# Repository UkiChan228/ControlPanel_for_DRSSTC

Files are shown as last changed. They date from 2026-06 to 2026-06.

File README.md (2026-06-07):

# ControlPanel for DRSSTC (RP2350)

Universal, open-source control panel for Dual Resonant Solid State Tesla Coils (DRSSTC) based on the Raspberry Pi RP2350.

Platform
Status

<br/>

### Table of Contents
<p>
  <a href="#-overview">Overview</a> <br/>
  <a href="#-status">Status</a> <br/>
  <a href="#-getting-started">Getting Started</a> <br/>
  <a href="#-hardware-choices">Hardware Choices</a> <br/>
  <a href="#-project-history">Project History</a>
</p>

<br/>

## 📒 Overview

This project is a dedicated, portable controller for **DRSSTC (Dual Resonant Solid State Tesla Coils)**. Built around the Raspberry Pi **RP2350**, it integrates reliable, high-frequency power management, an IPS touchscreen interface, and critical hardware-level safety features required for high-voltage control.

The primary goal is to provide a robust, noise-immune controller that can reliably send pulses to a Tesla coil over fiber optics without risking signal corruption from electromagnetic interference (EMI).

---

## ⚠️ Status

> [!WARNING]
> This project is currently in the **Alpha** development phase. The core hardware architecture is established, but firmware and features are actively being updated. Treat it as experimental.

---
### 3D Screenshot

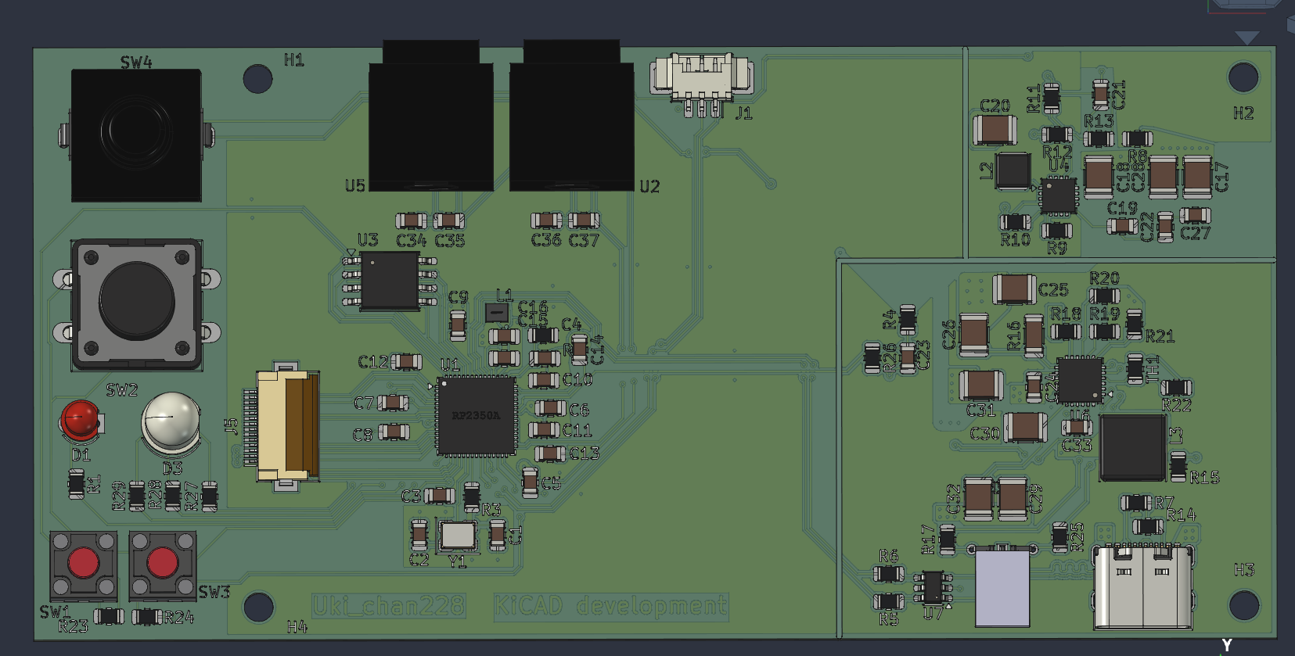
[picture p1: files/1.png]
Screnshoot1

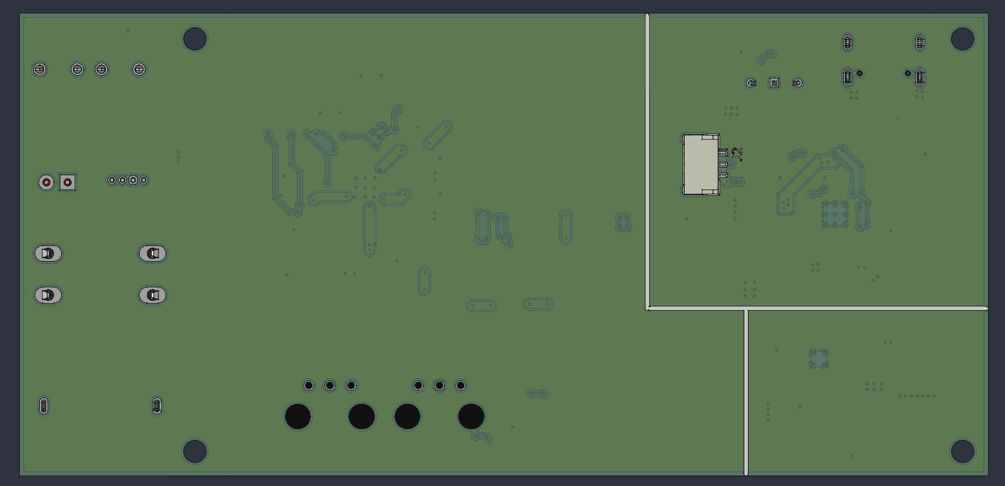
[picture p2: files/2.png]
Screnshoot2

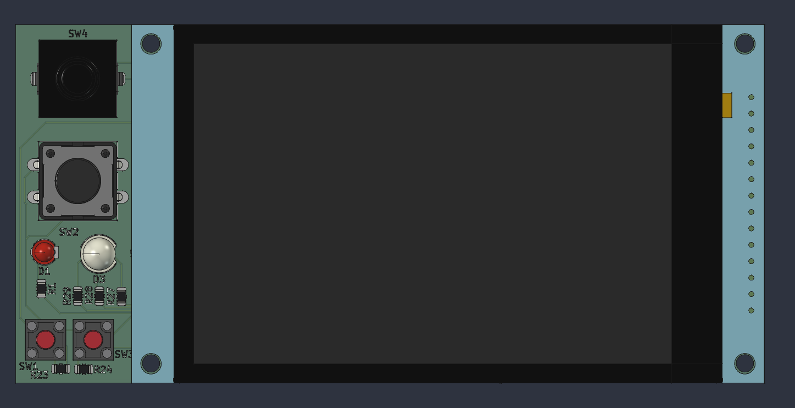
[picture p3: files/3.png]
Screnshoot3


---

## 🧑‍💻 Getting Started

To clone the repository along with the required submodules for graphics libraries and drivers, run:

```bash
# Clone the repository
git clone https://codeberg.org/uki_chan228/ControlPanel_for_DRSSTC  

# Initialize and update submodules and lvgl-9.5.0
cd ControlPanel_for_DRSSTC
git submodule update --init --recursive
```

---

## Hardware Architecture & Design Choices

### 1. MCU: Why RP2350 and not STM32?
Why did I choose the **RP2350** instead of something like the **STM32H507** or other H-series STM32 chips? It came down to high costs and counterfeits. If you want to buy an inexpensive **STM32** on AliExpress, almost all of them turn out to be clones or fakes. If you do manage to find an original, the price is quite steep. As a reliable example of genuine hardware, we can look at WeAct Studio. They have an excellent reputation, sell original dev boards, and their GitHub is an amazing resource containing schematics for all of their modules. Currently, the **RP2350** from **WeAct Studio** costs about $3. By comparison, the **STM32H** and **STM32G** series cost anywhere from $5.50 to $10. Of course, those offer more processing power and higher-quality peripherals like timers—after all, the STM32 architecture is time-tested and highly trusted. 

If we look at **STM32** alternatives, we should also mention Chinese compatible MCUs like the **AT32, GD32, APM32,** and CH32. These are essentially enhanced clones of the original **STM32**. Out of these four, GD32 (highly preferred) and **AT32** are the best choices and represent solid, reliable options to buy on AliExpress. 

But let's return to the RP2350. Its absolute killer feature is the PIO (Programmable I/O)—tiny state machines/microprocessors that run completely independently of the main CPU cores. The **RP2350** features three PIO blocks with 3 state machines each, giving you 12 independent processors in total. It is essentially a mini-FPGA built right into a microcontroller! This lets you implement almost any proprietary interface or even design your own. This is incredibly useful for my Remote Control project because I can send control pulses to a Tesla coil via fiber optics. I don't have to worry about what happens if the main processor hangs or if another button is pressed, because these tasks are handled by entirely separate hardware subsystems within the same silicon die.

In short, the RP2350 wins on cost-efficiency and unique features that can easily replace much more expensive **STM32** chips. Plus, it's a very new chip, which is also a great advantage.

### 2. Display and UI
The UI runs on an **MSP3526**, a 3.5-inch IPS display (480x320) with a capacitive touchscreen. The IPS panel allows for 16 million colors, making it comfortable to view real-time diagnostic graphs and navigate menus. 

*Safety feature:* To prevent accidental triggers, touchscreen interrupts are completely ignored at the firmware level while the RP2350 is actively transmitting pulses to the coil.

### 3. Power Supply
The board is powered by two **18650 Li-ion cells** mounted symmetrically for physical balance. 

For voltage regulation, I used the **TLV62130** step-down buck converter. I actually borrowed this idea from the Antminer S9 control boards (which use five of them). It operates at a high switching frequency (1.25MHz - 2.5MHz). Because of this high frequency, voltage ripple is minimal, and there is no need for massive filtering capacitors. It is also extremely durable, having been proven in harsh ASIC mining environments.

Charging the 2S battery pack is handled by an **IP2326** IC, which is a dedicated, highly efficient switching charger for 2-series lithium setups.

All components were selected so they can be easily sourced from AliExpress, allowing anyone to replicate this build.

---

## Project History & Acknowledgments

This project has been in active development from late January 2026 to June. It represents the time and effort of a single teenager fascinated by high-voltage engineering.

It originally started as a simple breadboard project with an ATmega328P, a character LCD1602, a rotary encoder, and a single start button. By mid-April, new ideas naturally pushed the development further, eventually evolving into the RP2350-based device you see today.

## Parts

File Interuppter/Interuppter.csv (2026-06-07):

Reference | Qty | Value | DNP | Exclude from BOM | Exclude from Board | Footprint | Datasheet
C1,C2 | 2 | 12pF |  |  |  | Capacitor_SMD:C_0805_2012Metric
C3,C6,C7,C8,C9,C10,C11,C12,C13,C23 | 10 | 0.1uF |  |  |  | Capacitor_SMD:C_0805_2012Metric
C4 | 1 | 4,7uF |  |  |  | Capacitor_SMD:C_0805_2012Metric
C5,C15,C16 | 3 | 4.7uF |  |  |  | Capacitor_SMD:C_0805_2012Metric
C14 | 1 | 2.2uF |  |  |  | Capacitor_SMD:C_0805_2012Metric
C17,C18,C25,C26,C28,C31,C32 | 7 | 10uF |  |  |  | Capacitor_SMD:C_1210_3225Metric
C19 | 1 | 33nF |  |  |  | Capacitor_SMD:C_0805_2012Metric
C20,C29,C30 | 3 | 22uF |  |  |  | Capacitor_SMD:C_1210_3225Metric
C21,C22,C24,C27,C33,C34,C36 | 7 | 100nF |  |  |  | Capacitor_SMD:C_0805_2012Metric
C35,C37 | 2 | 30pF |  |  |  | Capacitor_SMD:C_0805_2012Metric
D1 | 1 | LED_START |  |  |  | LED_THT:LED_D3.0mm
D2 | 1 |  |  |  |  | my_details:LED_AKA
D3 | 1 | LED_RAGB |  |  |  | LED_THT:LED_D5.0mm-4_RGB
J1,J2 | 2 | Conn_01x03 |  |  |  | Connector_Molex:Molex_PicoBlade_53261-0371_1x03-1MP_P1.25mm_Horizontal
J4 | 1 | USB_C_Receptacle_USB2.0_16P |  |  |  | Connector_USB:USB_C_Receptacle_G-Switch_GT-USB-7010ASV | https://www.usb.org/sites/default/files/documents/usb_type-c.zip
J5 | 1 | Display |  |  |  | Connector_FFC-FPC:Hirose_FH12-14S-0.5SH_1x14-1MP_P0.50mm_Horizontal
L1 | 1 | 3.3uH |  |  |  | RP2350_60QFN_minimal:L_pol_2016
L2 | 1 | 1uH |  |  |  | Inductor_SMD:L_Cenker_CKCS3012
L3 | 1 | 2.2uH |  |  |  | Inductor_SMD:L_APV_ANR6020
R1,R17,R25 | 3 | 220 |  |  |  | Resistor_SMD:R_0805_2012Metric
R2,R28,R29 | 3 | 33 |  |  |  | Resistor_SMD:R_0805_2012Metric
R3,R19,R20,R21,R23,R24 | 6 | 1k |  |  |  | Resistor_SMD:R_0805_2012Metric
R4 | 1 | 200k 1% |  |  |  | Resistor_SMD:R_0805_2012Metric
R5,R6 | 2 | 27 |  |  |  | Resistor_SMD:R_0805_2012Metric
R7,R14,R15 | 3 | 5.1k |  |  |  | Resistor_SMD:R_0805_2012Metric
R8,TH1 | 2 | 100k |  |  |  | Resistor_SMD:R_0805_2012Metric
R9 | 1 | 61.9k |  |  |  | Resistor_SMD:R_0805_2012Metric
R10 | 1 | 19.6k |  |  |  | Resistor_SMD:R_0805_2012Metric
R11 | 1 | 560k |  |  |  | Resistor_SMD:R_0805_2012Metric
R12 | 1 | 91k |  |  |  | Resistor_SMD:R_0805_2012Metric
R13 | 1 | 4.7M |  |  |  | Resistor_SMD:R_0805_2012Metric
R16 | 1 | 0.5 |  |  |  | Capacitor_SMD:C_1206_3216Metric
R18 | 1 | 90k |  |  |  | Resistor_SMD:R_0805_2012Metric
R22 | 1 | 82k |  |  |  | Resistor_SMD:R_0805_2012Metric
R26 | 1 | 100k 1% |  |  |  | Resistor_SMD:R_0805_2012Metric
R27 | 1 | 150 |  |  |  | Resistor_SMD:R_0805_2012Metric
SW1,SW3 | 2 | BUTTON |  |  |  | my_footprints:Tactile_Switch_6x6x7,3_H5.0
SW2 | 1 | BUT_START |  |  |  | Button_Switch_THT:SW_PUSH-12mm
SW4 | 1 | SW_SPST |  |  |  | my_footprints:PQZULK CB-1212-112D
U1 | 1 | RP2350A |  |  |  | Package_DFN_QFN:QFN-60-1EP_7x7mm_P0.4mm_EP3.4x3.4mm | https://datasheets.raspberrypi.com/rp2350/rp2350-datasheet.pdf
U2 | 1 | DRL2180_OUT |  |  |  | my_footprints:DRL2180
U3 | 1 | W25Q32JVSS |  |  |  | Package_SO:SOIC-8_5.3x5.3mm_P1.27mm | http://www.winbond.com/resource-files/w25q32jv%20revg%2003272018%20plus.pdf
U4 | 1 | TLV62130RGT |  |  |  | Package_DFN_QFN:VQFN-16-1EP_3x3mm_P0.5mm_EP1.8x1.8mm_ThermalVias
U5 | 1 | DRL2180_IN |  |  |  | my_footprints:DRL2180
U6 | 1 | IP2326 |  |  |  | Package_DFN_QFN:QFN-24-1EP_4x4mm_P0.5mm_EP2.7x2.7mm_ThermalVias
U7 | 1 | USBLC6-2SC6 |  |  |  | Package_TO_SOT_SMD:SOT-23-6 | https://www.st.com/resource/en/datasheet/usblc6-2.pdf
Y1 | 1 | 12MHz |  |  |  | Crystal:Crystal_SMD_3225-4Pin_3.2x2.5mm

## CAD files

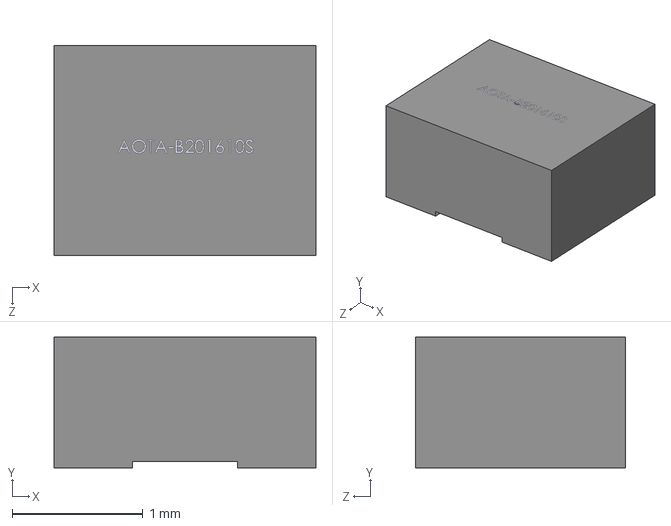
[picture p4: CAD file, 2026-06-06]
Interuppter/3d model/AOTA-B201610S.STEP
2.00 x 1.00 x 1.60 mm

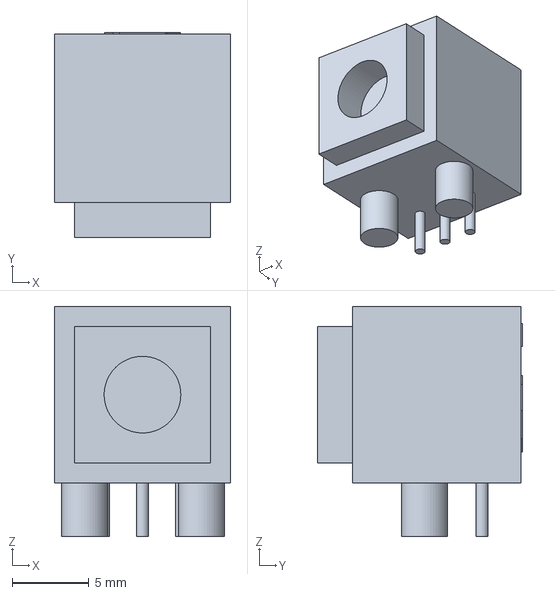
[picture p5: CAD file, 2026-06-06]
Interuppter/3d model/DLR2180-без крепления сверху.step
11.5 x 13.4 x 15.0 mm

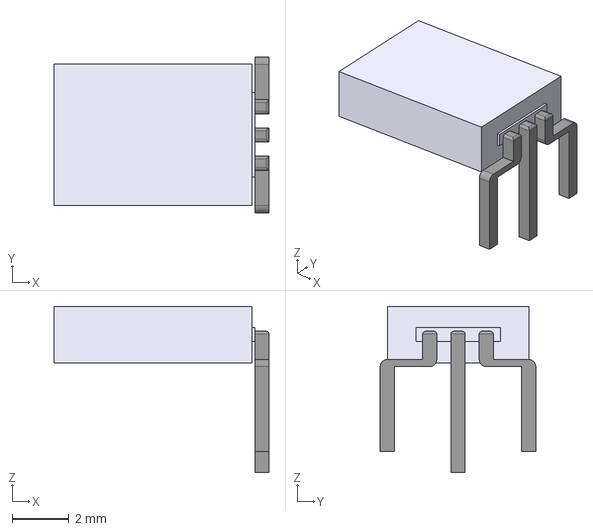
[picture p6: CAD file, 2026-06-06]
Interuppter/3d model/LED_AKK.step
7.60 x 5.50 x 5.88 mm

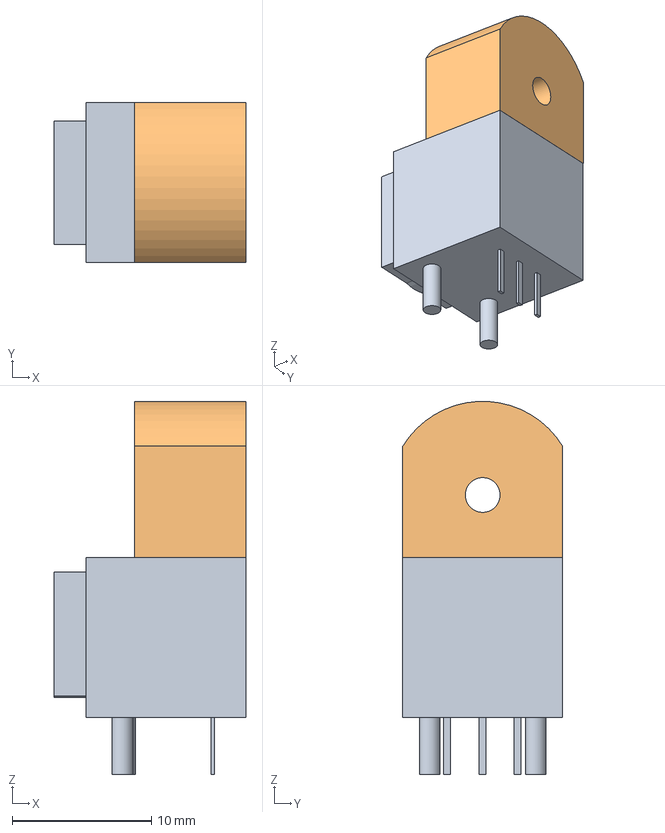
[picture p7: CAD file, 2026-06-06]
Interuppter/3d model/DLR2180.step
13.8 x 11.5 x 26.8 mm

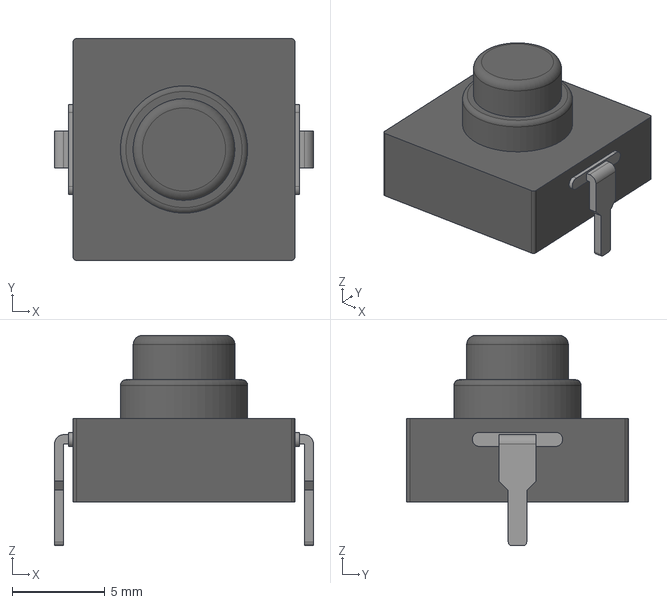
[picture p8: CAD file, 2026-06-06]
Interuppter/3d model/PQZULK CB-1212-112D.step
14.0 x 12.0 x 11.4 mm

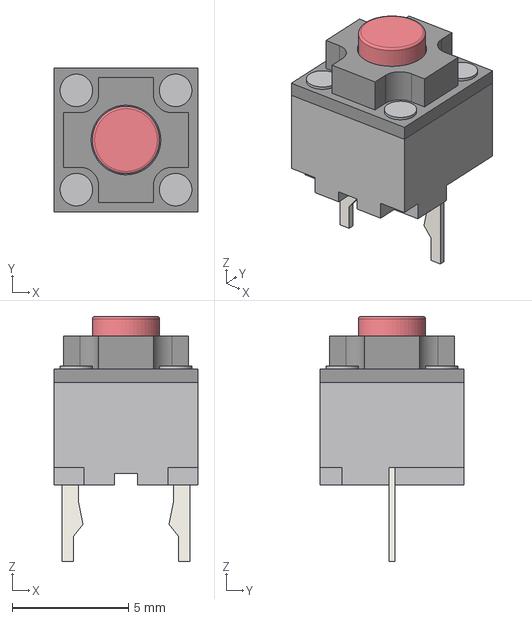
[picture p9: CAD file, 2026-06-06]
Interuppter/3d model/microSwitch_Kailh_6x6x7.3 (MI627301D07).step
6.20 x 6.20 x 10.6 mm

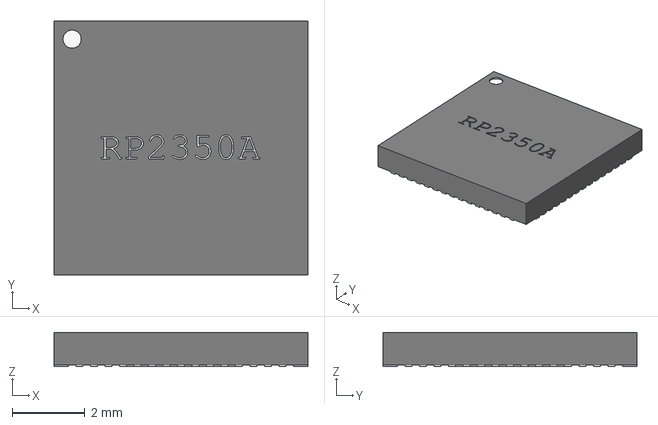
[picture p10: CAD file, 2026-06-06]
Interuppter/3d model/RP2350_QFN60.step
7.00 x 7.00 x 0.95 mm

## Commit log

2026-05-23 Начальный комит инициализации. Первые строки прерывание по тачскрину
2026-06-06 Files KiCAD pcb and sch+
    [DLR2180-без крепления сверху.step, DLR2180.step, Interuppter.kicad_pcb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]
2026-06-06 Update KiCAD and add GERBER files and 3D screenshots
    [Interuppter-B_Cu.gbr, Interuppter-B_Mask.gbr, Interuppter-B_Paste.gbr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]
2026-06-08 Update C++ code
    [Interuppter.kicad_pcb, Interuppter.kicad_sch]
2026-06-08 Update C++ code. Added headers and drivers for I2C pio and SPI PIO
    [Interuppter.kicad_pcb]
